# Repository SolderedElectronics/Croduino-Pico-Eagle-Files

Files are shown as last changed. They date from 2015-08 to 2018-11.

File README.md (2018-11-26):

# Croduino Pico Eagle Files
## Image
Croduino Pico image
[Croduino Pico(100010)](https://e-radionica.com/en/croduino-pico.html)

## Description and details
Croduino Pico is a sequel to Croduino Basic board. It is simpler than the Basic version since it doesn't have FTDI converter on-board so it needs another board which has one for programming(Croduino Basic, for example). It is imagined to be used for leaving in projects and products.

###Specs:
- Atmega328 microcontroller(32kB flash, 2kB RAM, 0.5kB EEPROM)
- 22 I/O pins, 14 digital I/O, 6 PWM, 8 analog pins
- Size only 3 x 5cm
- LED light on the 13th pin
- Voltage regulator for possibility of external charging
- Made in Croatia (EU)
- Free lifetime technical support at techsupport@e-radionica.com
- Should be set up as "Arduino Nano w/ Atmega328" in Arduino software.

Microcontroller on-board is loaded with Arduino Optiboot bootloader.

## Repository content
This repo contains Cadsoft Eagle .sch and .brd files for Croduino Pico board. It also contains schematic in .pdf created from .sch Eagle file. 
Files have been arranged into folders for navigating between different versions of board. 
Tip: layer 200 shows top silkscreen and layer 208 should be bottom silkscreen. tParts and bParts is not used.

## Docs
- [Croduino Pico product page] (https://e-radionica.com/en/croduino-pico.html)
- [Croduino lessons - on croatian language] (https://vimeo.com/channels/croduino)

## Board versions
- v1.0 - inital version

## License info
This product is open-source. Yay!
For any tech questions, contact us at techsupport@e-radionica.com
If you find an Issue, please open one at GitHub. If you can improve our product, fork us.

e-radionica.com Team.

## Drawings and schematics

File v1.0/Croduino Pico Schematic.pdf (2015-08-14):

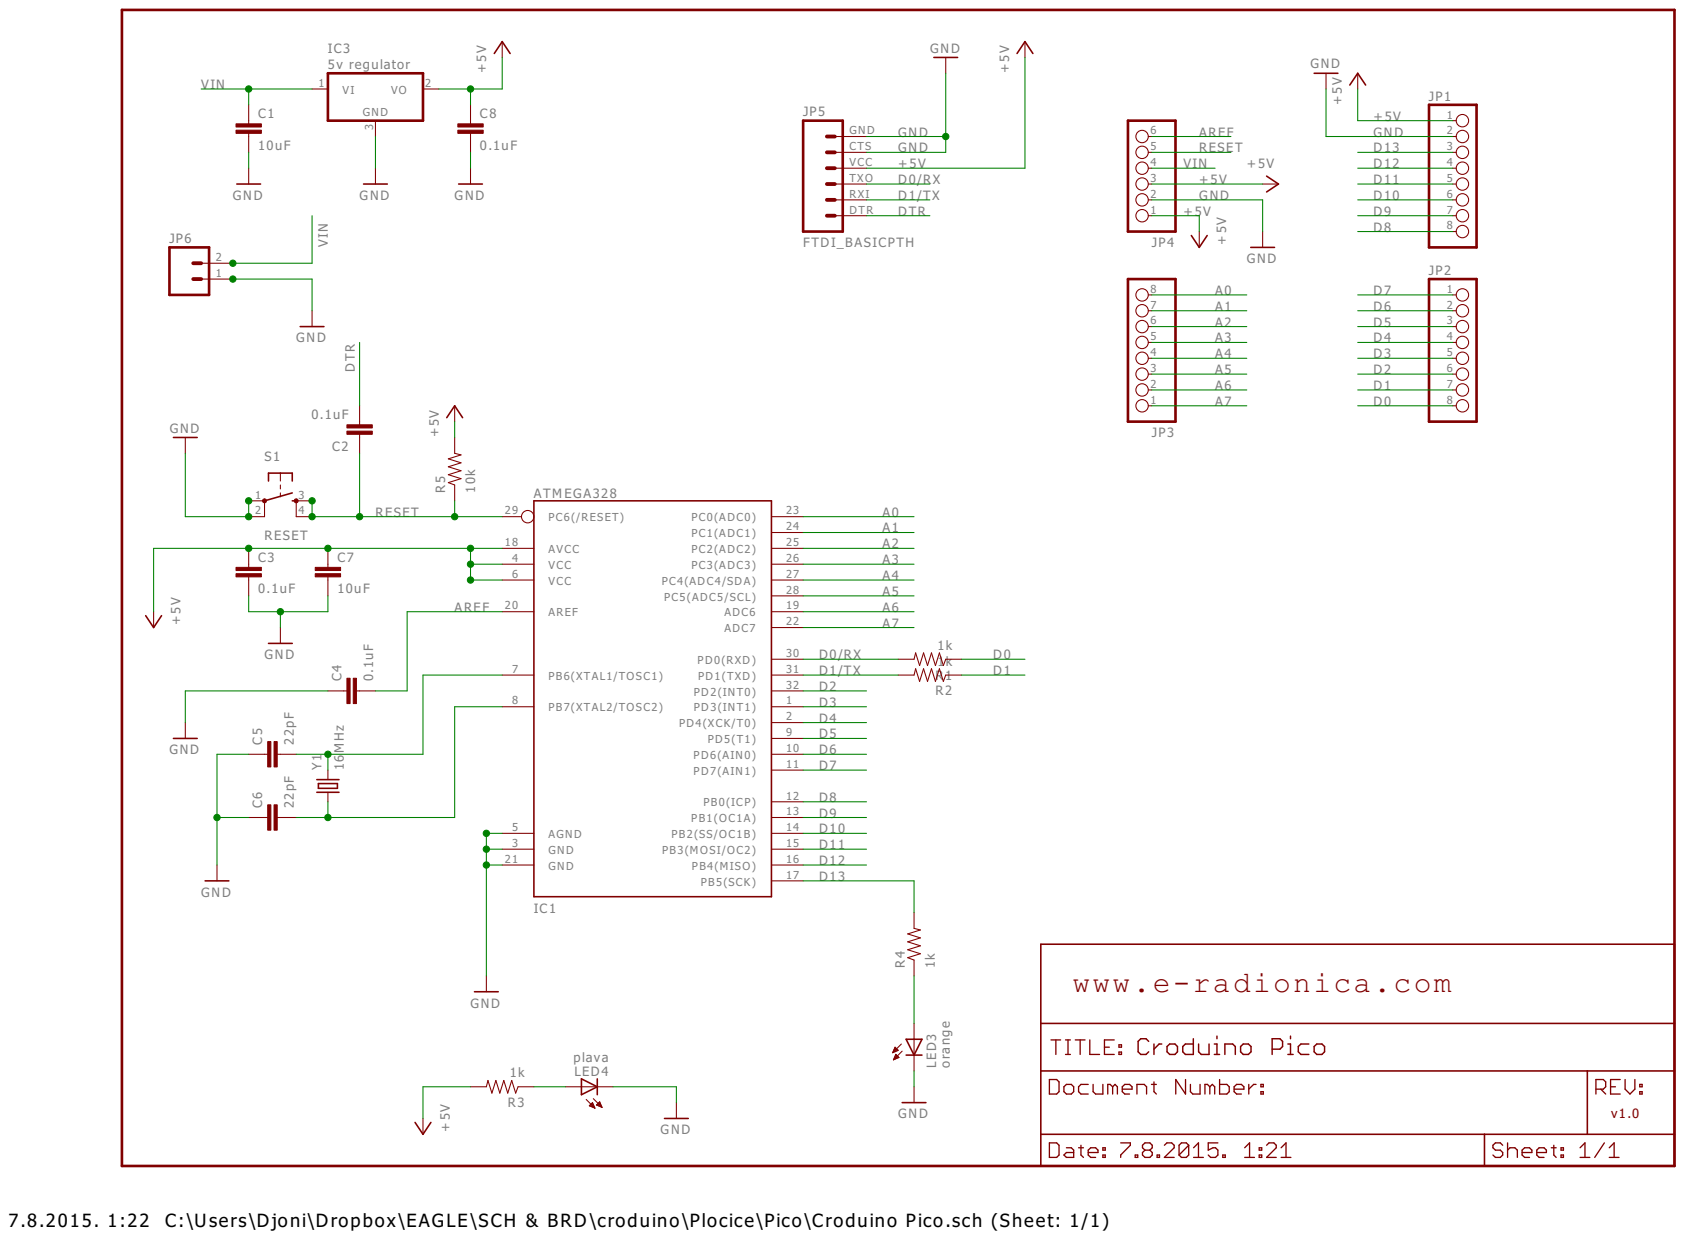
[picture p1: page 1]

7.8.2015. 1:22 C:\Users\Djoni\Dropbox\EAGLE\SCH & BRD\croduino\Plocice\Pico\Croduino Pico.sch (Sheet: 1/1)

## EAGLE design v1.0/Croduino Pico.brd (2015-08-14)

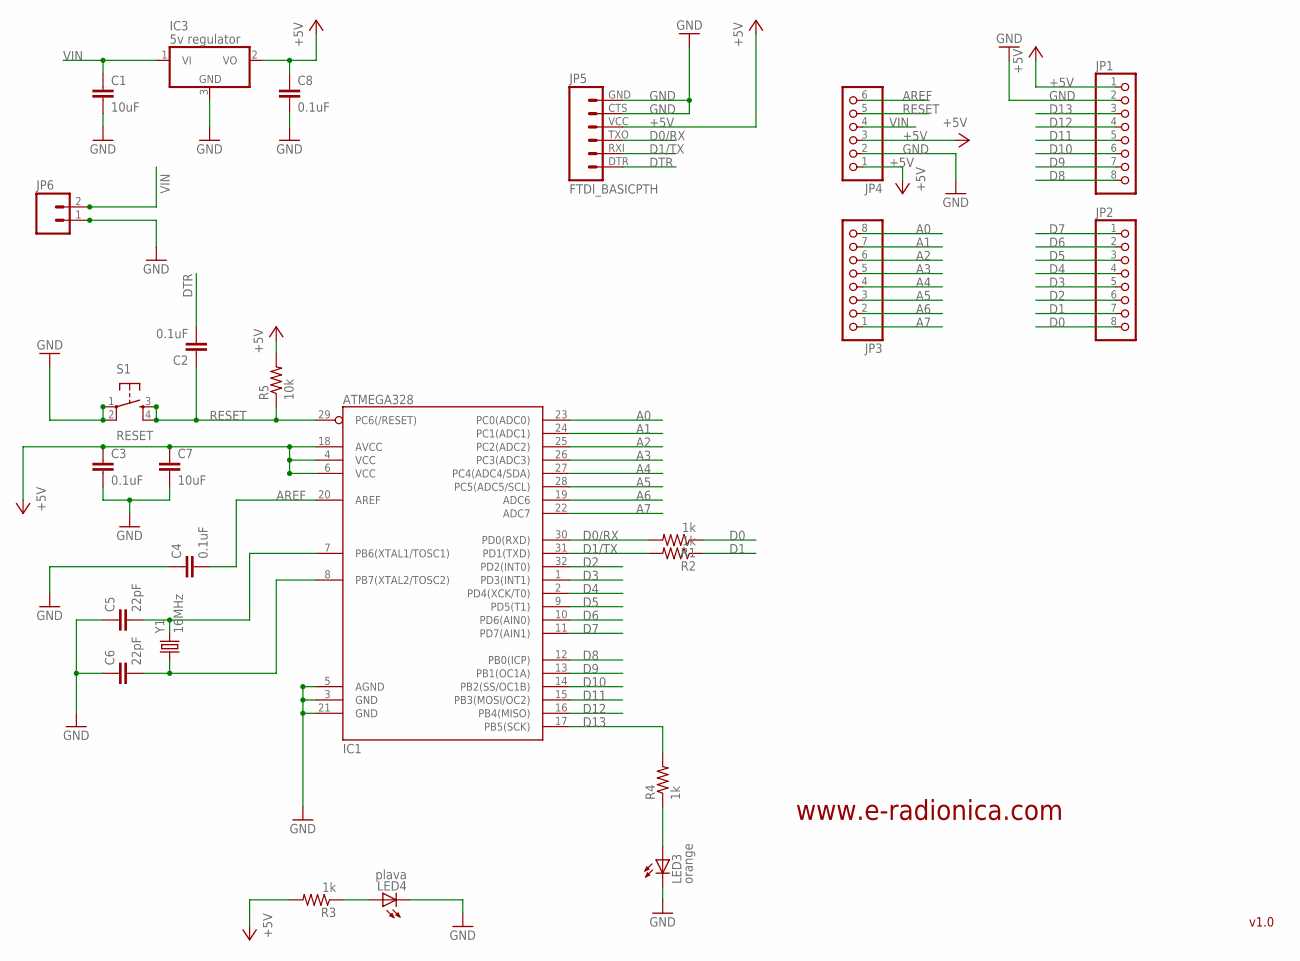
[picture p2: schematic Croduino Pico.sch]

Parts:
C1, C7: 10uF; C3216
C2, C3, C4, C8: 0.1uF; 0603-CAP
C5, C6: 22pF; 0603-CAP
IC1: ATMEGA328; TQFP32-08
IC3: 5v regulator; TO252
JP1, JP2, JP3: PINHD-1X8BIG; 1X08-BIG
JP4: PINHD-1X6B; 1X06-BIG
JP5: FTDI_BASICPTH; FTDI_BASIC
JP6: M02LOCK_LONGPADS; 1X02_LOCK_LONGPADS
LED3: orange; CHIP-LED0805
LED4: plava; CHIP-LED0805
R1, R2, R3, R4: 1k; 0603-RES
R5: 10k; 0603-RES
S1: RESET; TACTILE_SWITCH_SMD
Y1: 16MHz; CRYSTAL-SMD-5X3

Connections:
+5V: C3.1, C7.1, C8.1, IC1.4 (VCC), IC1.6 (VCC), IC1.18 (AVCC), IC3.2 (VO), JP1.1, JP4.1, JP4.3, JP5.VCC (4), R3.2, R5.2
A0: IC1.23 (PC0(ADC0)), JP3.8
A1: IC1.24 (PC1(ADC1)), JP3.7
A2: IC1.25 (PC2(ADC2)), JP3.6
A3: IC1.26 (PC3(ADC3)), JP3.5
A4: IC1.27 (PC4(ADC4/SDA)), JP3.4
A5: IC1.28 (PC5(ADC5/SCL)), JP3.3
A6: IC1.19 (ADC6), JP3.2
A7: IC1.22 (ADC7), JP3.1
AREF: C4.2, IC1.20 (AREF), JP4.6
CRYSTAL1: C5.2, IC1.7 (PB6(XTAL1/TOSC1)), Y1.3 (2)
CRYSTAL2: C6.2, IC1.8 (PB7(XTAL2/TOSC2)), Y1.1
D0: JP2.8, R1.1
D0/RX: IC1.30 (PD0(RXD)), JP5.TXO (3), R1.2
D1: JP2.7, R2.1
D1/TX: IC1.31 (PD1(TXD)), JP5.RXI (2), R2.2
D2: IC1.32 (PD2(INT0)), JP2.6
D3: IC1.1 (PD3(INT1)), JP2.5
D4: IC1.2 (PD4(XCK/T0)), JP2.4
D5: IC1.9 (PD5(T1)), JP2.3
D6: IC1.10 (PD6(AIN0)), JP2.2
D7: IC1.11 (PD7(AIN1)), JP2.1
D8: IC1.12 (PB0(ICP)), JP1.8
D9: IC1.13 (PB1(OC1A)), JP1.7
D10: IC1.14 (PB2(SS/OC1B)), JP1.6
D11: IC1.15 (PB3(MOSI/OC2)), JP1.5
D12: IC1.16 (PB4(MISO)), JP1.4
D13: IC1.17 (PB5(SCK)), JP1.3, R4.2
DTR: C2.2, JP5.DTR (1)
GND: C1.2, C3.2, C4.1, C5.1, C6.1, C7.2, C8.2, IC1.3 (GND), IC1.5 (AGND), IC1.21 (GND), IC3.3 (GND), JP1.2, JP4.2, JP5.CTS (5), JP5.GND (6), JP6.1, LED3.C, LED4.C, S1.1, S1.2
unnamed: LED3.A, R4.1
unnamed: LED4.A, R3.1
RESET: C2.1, IC1.29 (PC6(/RESET)), JP4.5, R5.1, S1.3, S1.4
VIN: C1.1, IC3.1 (VI), JP4.4, JP6.2

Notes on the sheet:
v1.0
www.e-radionica.com

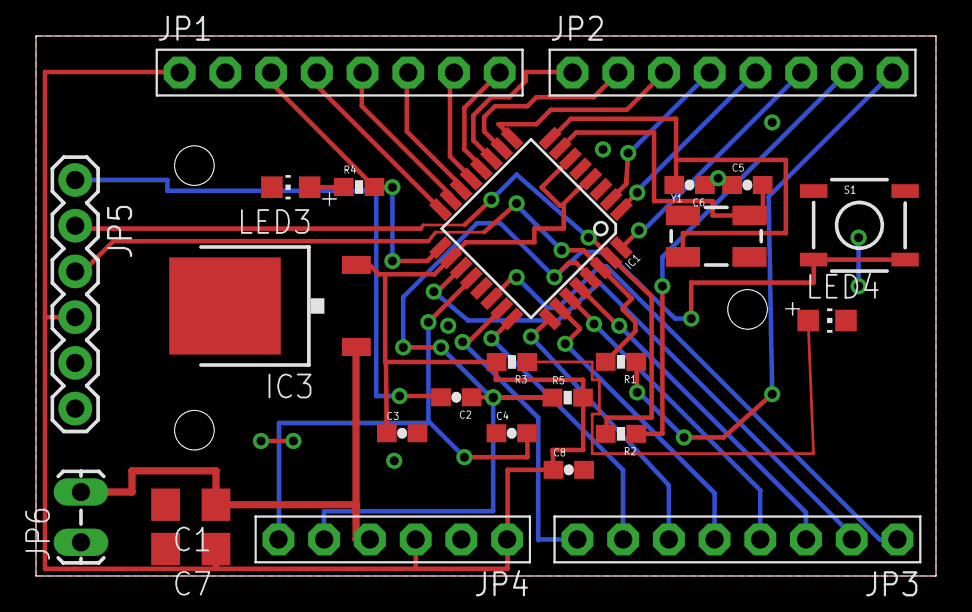
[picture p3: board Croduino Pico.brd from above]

Board: 2 copper layers, 50.0 x 30.0 mm, 27 parts (0 on the bottom side), 34 nets.

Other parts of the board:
U$1: PICOO
U$2: UTICNICA3MM

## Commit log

2015-08-14 Adding actual files to Repo
    [Croduino Pico.brd, Croduino Pico.sch]
2015-08-24 Write Readme, add version folder
    [Croduino Pico.brd, Croduino Pico.sch]

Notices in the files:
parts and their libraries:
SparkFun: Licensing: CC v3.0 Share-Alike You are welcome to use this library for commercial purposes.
